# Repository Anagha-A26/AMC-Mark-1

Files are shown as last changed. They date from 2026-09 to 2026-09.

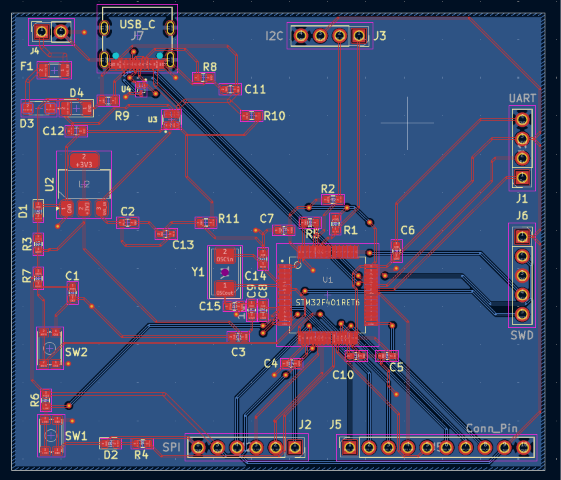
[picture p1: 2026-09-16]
STMt1/Images/PCB_Top.png

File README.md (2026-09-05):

# AMC-Mark-1
KiCad-based 2-layer STM32F401RE evaluation board with USB, UART, SPI, I²C, SWD, GPIO expansion, power regulation and user interfaces.

**STM32F401RE DEVELOPMENT BOARD**

**1. Selected MCU & Design Concept**

**Selected MCU**

**STM32F401RE / STM32F401RET6**

The **STM32F401RE** is selected as the core microcontroller for the evaluation board. It is based on an **Arm Cortex-M4 processor with Floating Point Unit (FPU)** and provides a broad set of peripherals, including GPIO, timers, ADC, UART/USART, SPI, I²C, USB 2.0 Full-Speed and SWD/JTAG debugging capabilities.
The MCU was selected because its peripheral set allows the major requirements of the evaluation board to be implemented around a **single central processing device**, while providing sufficient GPIO for external expansion.

**Why STM32F401RE?**

The core objective is to develop a **compact evaluation platform around the STM32F401RE** that allows users to:

- Program and debug the MCU through SWD.
- Communicate with a PC or USB host through USB.
- Experiment with UART, SPI and I²C peripherals.
- Access additional GPIOs for external circuits and modules.
- Interact with the board through user buttons and LEDs.
- Evaluate the MCU in a practical embedded-system development environment.

Thus, the STM32F401RE acts as the **central hub connecting the processing, communication, debugging and expansion interfaces**.

**Design Concept**

We propose a **compact, custom 2-layer STM32F401RE evaluation board** designed to provide convenient access to the MCU's processing, communication, debugging and GPIO capabilities.
The design is **functionally inspired by the STM32 NUCLEO-F401RE**, which provides STM32 development, Arduino compatibility, ST Morpho expansion and integrated ST-LINK debugging.
However, instead of reproducing the Nucleo architecture, our design independently implements the required functionality with a simpler and more focused architecture.

**Key design approach**

- **STM32F401RE** as the central MCU.
- **External ST-Link through SWD**, avoiding duplication of the on-board ST-LINK circuitry.
- **USB Type-C** providing direct USB 2.0 connectivity to the STM32.
- Dedicated and clearly labelled **UART, SPI and I²C interfaces**.
- **GPIO expansion headers** for external experimentation.
- Dedicated **reset button, user button, user LED and power indication**.
- Custom **power distribution, decoupling and grounding strategy**.
- Independently designed **2-layer PCB layout and routing** within the competition's 100 mm × 100 mm limit.

**Core Design Idea**

> To create a compact and accessible STM32F401RE evaluation platform that brings the MCU's major communication, debugging and GPIO capabilities onto a single independently designed 2-layer PCB, allowing users to program, debug and experiment with the MCU and external peripherals without reproducing the complete Nucleo architecture.

---

**Design Objectives**

1. Develop a functional **STM32F401RE evaluation platform**.
2. Provide **USB Type-C USB 2.0 connectivity** to the MCU.
3. Provide accessible **UART, SPI and I²C interfaces**.
4. Provide **SWD programming and debugging** using an external programmer/debugger.
5. Provide **user reset, user button, user LED and power indication**.
6. Provide **GPIO expansion headers** with power and ground.
7. Implement appropriate **power regulation and local decoupling**.
8. Develop a compact and electrically complete **2-layer PCB within 100 mm × 100 mm**.
9. Independently design the **schematic, component selection, placement, routing and silkscreen** rather than reproducing the reference board.

**2. BLOCK DIAGRAM**

ChatGPT Image Sep 5, 2026, 11_15_35 PM

**3. Schematic progress**




[View Schematic and PCB PDF](./schematic_pcb.pdf)

**4. Components Used**

| **Sl. No.** | **Component Type** | **Value / Part Number** | **Quantity** | **Section / Function** |
| --- | --- | --- | --- | --- |
| 1 | Microcontroller | STM32F401RET6 | 1 | Main MCU |
| 2 | Voltage Regulator | AMS1117-3.3 | 1 | 5 V to 3.3 V regulation |
| 3 | USB Type-C Connector | USB\_C\_Receptacle\_USB2.0\_16P | 1 | USB communication and 5 V input |
| 4 | Pin Header / Connector | Conn\_01x02\_Pin | 1 | External 5 V / GND connection |
| 5 | Pin Header | Conn\_01x05\_Pin | 1 | SWD programming/debugging |
| 6 | Pin Header | Conn\_01x04\_Pin | 1 | UART interface |
| 7 | Pin Header | Conn\_01x06\_Pin | 1 | SPI interface |
| 8 | Pin Header | Conn\_01x04\_Pin | 1 | I²C interface |
| 9 | Pin Header | Conn\_01x10\_Pin | 1 | GPIO expansion |
| 10 | Push Button | SW\_Push | 1 | User button |
| 11 | Push Button | SW\_Push | 1 | Reset button |
| 12 | LED | LED | 1 | Power ON indicator |
| 13 | LED | LED | 1 | User-programmable LED |
| 14 | Resistor | 4.7 kΩ | 1 | I²C SCL pull-up |
| 15 | Resistor | 4.7 kΩ | 1 | I²C SDA pull-up |
| 16 | Resistor | 1 kΩ | 1 | Power LED current limiting |
| 17 | Resistor | 330 Ω | 1 | User LED current limiting |
| 18 | Resistor | 10 kΩ | 1 | BOOT0 pull-down |
| 19 | Resistor | 10 kΩ | 1 | User button pull-up |
| 20 | Resistor | 10 kΩ | 1 | NRST pull-up |
| 21 | Resistor | 5.1 kΩ | 1 | USB-C CC1 pull-down |
| 22 | Resistor | 5.1 kΩ | 1 | USB-C CC2 pull-down |
| 23 | Capacitor | 10 µF | 1 | AMS1117 input capacitor |
| 24 | Capacitor | 10 µF | 1 | AMS1117 output capacitor |
| 25 | Power Multiplexer | TPS2116DRLR | 1 | Priority selection between USB-C 5 V and external 5 V power inputs |

**5. Major design decisions**

- Selected USB Type-C as the USB connector for communication and power input.
- Designed the board to accept 5 V power from either USB-C or an external 5 V connector.
- Selected the AMS1117-3.3 voltage regulator to generate the required 3.3 V supply.
- Used an external ST-Link through the SWD header instead of including an onboard ST-Link debugger.
- Selected PA11 and PA12 for USB D− and D+ communication.
- Selected PA9 and PA10 for UART TX and RX.
- Selected PA4, PA5, PA6 and PA7 for SPI communication.
- Selected PB6 and PB7 for I²C communication.
- Used 4.7 kΩ pull-up resistors for the I²C SCL and SDA lines.
- Used 5.1 kΩ pull-down resistors on CC1 and CC2 to configure the USB-C connector for device operation.
- Pulled BOOT0 to GND using a 10 kΩ resistor to ensure normal boot from internal Flash memory.
- Used separate headers for UART, SPI, I²C, SWD and GPIO expansion for easier testing and external interfacing.
- Selected additional unused MCU pins and brought them out through a dedicated GPIO expansion header.
- Used separate Power ON LED and User LED to distinguish power status from software-controlled indication.
- Chose a simple push-button reset circuit with a pull-up resistor for reliable manual reset.

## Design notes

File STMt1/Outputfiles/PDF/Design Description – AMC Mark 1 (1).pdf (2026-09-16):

# AMC Mark 1

### Team: AMC

1. Amal Manoj C
2. Anagha A
3. George Thomas

## 1. Design Objective

The proposed design is a compact, two-layer STM32F401RE-based evaluation and development board inspired by the functionality and architecture of the STM32 NUCLEO-F401RE. The objective is to provide a practical development platform with the essential facilities required for programming, debugging, power management, communication, GPIO expansion, and user interaction.

The board uses the STM32F401RET6 as the main microcontroller and integrates USB connectivity, regulated 3.3 V power, SWD programming/debugging, UART, SPI, I²C, GPIO expansion, user buttons, and status LEDs.

The design was developed independently using KiCad, with emphasis on compact component placement, reliable power distribution, organized routing, proper decoupling, and a clear PCB silkscreen.

The PCB was designed with a 70 mm × 60 mm board size, which is well within the competition's maximum permitted size of 100 mm × 100 mm. The design uses exactly two copper layers (Top and Bottom), with both layers utilized for efficient signal routing and power/ground distribution. The compact 70 mm × 60 mm form factor was chosen to achieve efficient component placement while maintaining clear routing, adequate spacing, and good overall board organization.

## 2. Main Components and Features

The major components and functional blocks incorporated in the board are:

- STM32F401RET6 – Main 32-bit ARM Cortex-M4 microcontroller
- USB Type-C interface – USB connectivity for the board
- TPS2116DRL power multiplexer – Power-source selection/management
- AMS1117-3.3 regulator – Generation of the regulated 3.3 V supply
- TPD2EUSB30 – USB protection
- SWD header – Programming and debugging interface

- UART header – Serial communication
- SPI header – High-speed peripheral communication
- I²C header – Two-wire peripheral communication
- GPIO expansion header – Access to STM32 GPIO pins
- Reset button – Hardware reset functionality
- User button – General-purpose user input
- User LED – User/status indication
- Power LED – Power status indication
- Crystal oscillator – External clock source for the microcontroller
- Decoupling capacitors – Local power-supply stabilization
- Protection components – Input and USB protection

## 3. Power Architecture

The power architecture was designed to support both USB-C 5 V and an external 5 V input. The TPS2116DRL power multiplexer provides controlled power-source selection and supplies the SYS_5V rail. This is followed by the AMS1117-3.3 regulator, which generates the regulated 3.3 V supply for the STM32F401RET6 and associated peripherals. This architecture provides a flexible power-input arrangement while maintaining a regulated supply for the low-voltage circuitry.

The basic power flow is

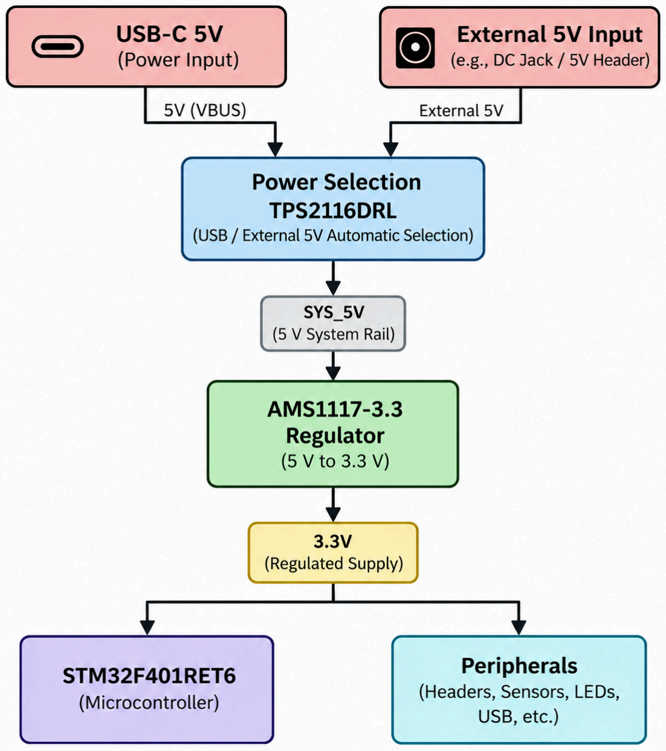
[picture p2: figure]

The power architecture supports two 5 V input sources: USB-C 5 V and an external 5 V supply. These inputs are connected to the TPS2116DRL power multiplexer, which provides controlled selection and distribution of the available power source to the SYS_5V rail. The SYS_5V rail then feeds the AMS1117-3.3 regulator, which generates the regulated 3.3 V supply required by the STM32F401RET6 and associated low-voltage circuitry.

A dedicated power LED provides visual indication that the board is powered. The resulting architecture provides the essential functionality required for an STM32 evaluation and development platform while maintaining a compact PCB implementation.

## 4. PCB Design

The PCB was designed as a two-layer board, consisting of top and bottom copper layers. The maximum permitted board size for the competition is 100 mm × 100 mm, and the board layout was developed within this constraint.

Component placement was carried out according to functional requirements and routing convenience. The STM32F401RET6 is positioned as the central processing element, while connectors and interfaces are arranged around the board to provide convenient access during development.

The major PCB design considerations were

- Compact component placement
- Proper power and ground distribution
- Short connections for critical power paths
- Appropriate placement of decoupling capacitors
- Organized signal routing
- Separation and organization of different functional interfaces
- Efficient use of both copper layers
- Accessible programming and communication headers
- Clear and readable PCB silkscreen

The final PCB passed the KiCad DRC with zero errors, with zero unrouted connections. The silkscreen was also organized to clearly identify important connectors, interfaces, power rails, and user controls.

## 5. Interfaces

### 5.1 SWD Interface

A dedicated SWD (Serial Wire Debug) header is provided for programming and debugging the STM32F401RET6. The interface provides the required connections.

- SWDIO
- SWCLK
- NRST
- VCC
- GND

The ST-Link circuitry itself is not included on the board, as it is not required by the competition specification. An external ST-Link programmer/debugger can therefore be connected through the SWD header.

### 5.2 UART Interface

A dedicated UART header is provided for serial communication with external devices. This interface can be used for debugging, terminal communication, data logging, and communication with other embedded systems.

### 5.3 SPI Interface

An SPI header provides access to the STM32 SPI peripheral signals. It can be used to interface external sensors, displays, memory devices, ADCs, DACs, and other SPI-compatible peripherals.

### 5.4 I²C Interface

An I²C header is provided for connecting multiple peripheral devices using the two-wire I²C communication protocol. This makes the board suitable for interfacing sensors, displays, EEPROMs, and other I²C devices.

### 5.5 USB Interface

A USB Type-C connector is provided as the primary USB interface. The USB section also includes dedicated protection circuitry to improve the robustness of the USB connection.

### 5.6 GPIO Expansion

A dedicated GPIO expansion header provides access to selected STM32 GPIO, power, and ground connections. This allows external circuits and modules to be connected easily during development and experimentation.

## 6. Design Decisions

Several design decisions were made to achieve a compact and functional evaluation board.

Power Management

The power architecture was designed to support both USB-C 5 V and an external 5 V input. The TPS2116DRL power multiplexer provides controlled power-source selection and supplies the SYS_5V rail. This is followed by the AMS1117-3.3 regulator, which generates the regulated 3.3 V supply for the STM32F401RET6 and associated peripherals. This architecture provides a flexible power-input arrangement while maintaining a regulated supply for the low-voltage circuitry.

Component Placement

The STM32F401RET6 was positioned as the central component of the PCB, with supporting power and clock components placed close to the MCU. Connectors were positioned around the board edges where possible to make external connections easier.

Interface Organization

Communication and programming interfaces were separated into dedicated headers for SWD, UART, SPI, and I²C. This makes the board easier to use and allows different peripherals or debugging equipment to be connected without interfering with other interfaces.

Routing Optimization

The PCB routing was planned to minimize unnecessary trace lengths and reduce routing complexity. Power connections and important signal paths were given appropriate routing consideration, while the two copper layers were utilized efficiently to complete the design within the board-size and layer constraints.

Ground and Power Distribution

Ground and power connections were distributed throughout the PCB with attention to maintaining reliable connections between the power supply, microcontroller, and peripheral circuits. Decoupling capacitors were placed near relevant power pins to provide local supply stabilization.

Silkscreen and Usability

Clear silkscreen labels were provided for major connectors, interfaces, power rails, buttons, LEDs, and other important board features. This improves usability by allowing users to identify the purpose and pin functions of the different headers directly from the PCB.

## 7. Conclusion

The resulting STM32F401RE evaluation board provides a compact and organized development platform centered around the STM32F401RET6 microcontroller. It integrates regulated power, USB connectivity, SWD debugging, UART, SPI, I²C, GPIO expansion, user controls, and status indicators in a two-layer PCB.

The design focuses on electrical completeness, practical component placement, organized routing, power integrity, and usability. The PCB was developed independently in KiCad while using the STM32 NUCLEO-F401RE as a functional reference, in accordance with the competition requirements. The final design is intended to provide a practical platform for STM32-based embedded development and peripheral interfacing.

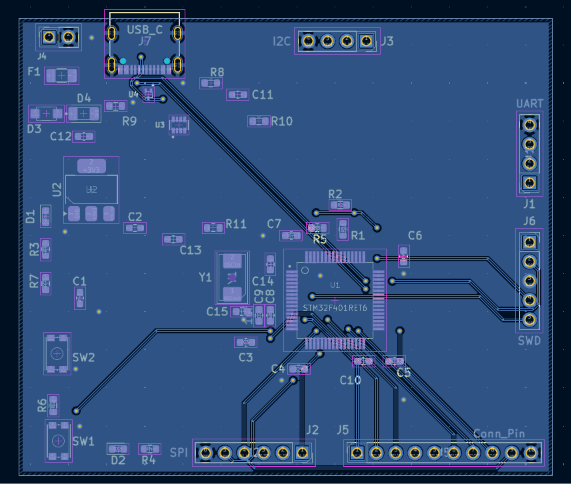
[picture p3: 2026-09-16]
STMt1/Images/PCB_Bottom.png

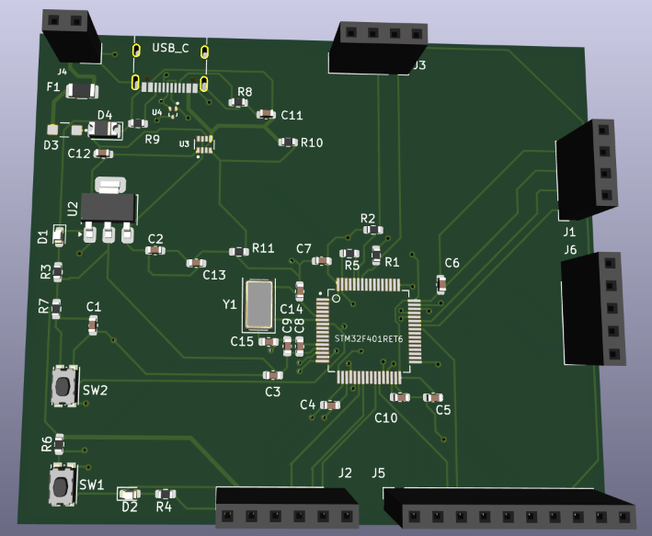
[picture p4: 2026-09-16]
STMt1/Images/PCB_3D_Front.png

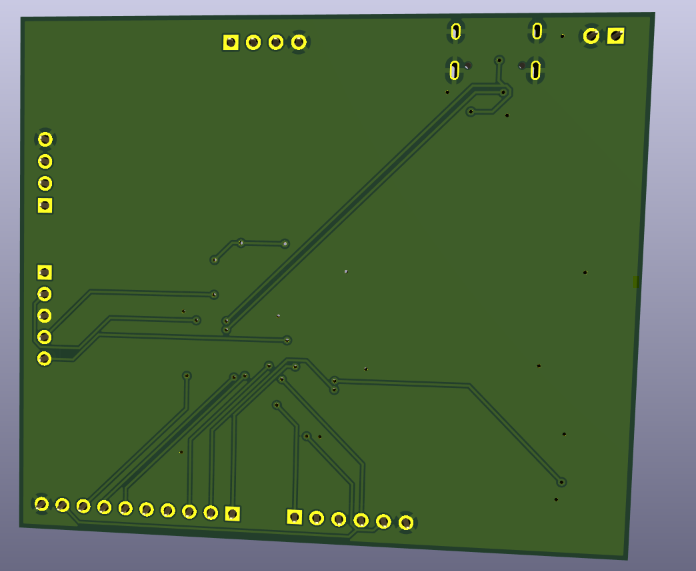
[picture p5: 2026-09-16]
STMt1/Images/PCB_3D_Back.png

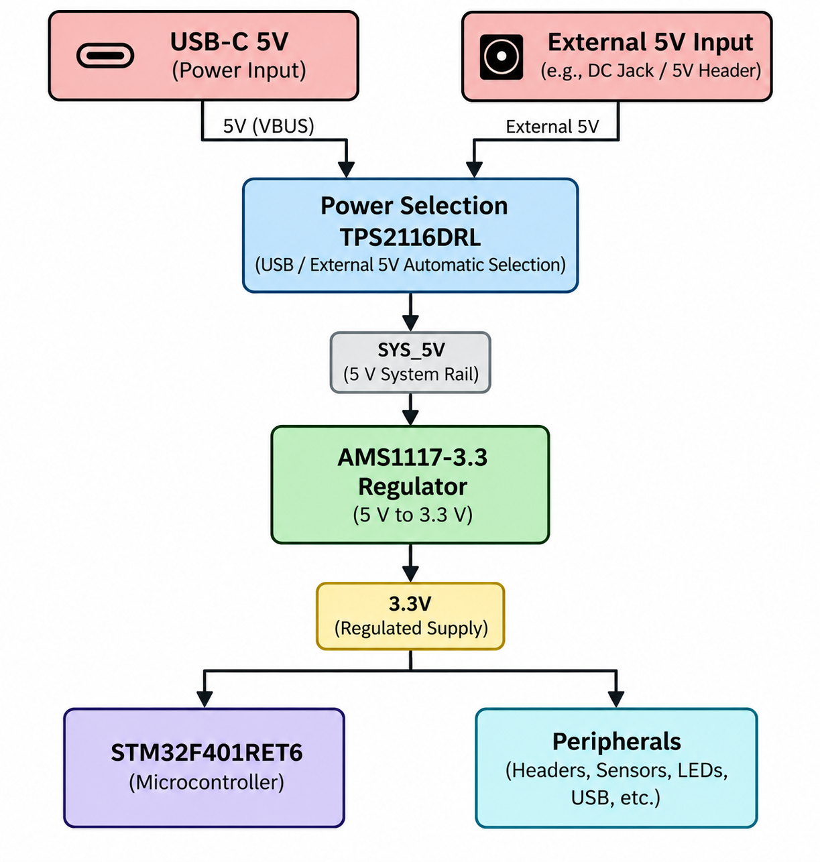
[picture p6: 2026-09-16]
STMt1/Images/Power_Arch.png

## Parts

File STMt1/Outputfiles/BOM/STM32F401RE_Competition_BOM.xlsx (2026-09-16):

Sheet: Competition BOM
STM32F401RE Evaluation Board – Competition BOM
AMC Mark 1 Estimated component cost in INR
Reference | Qty | Value / Part | Footprint | Unit Cost (₹) | Total Cost (₹) | Price Basis / Note
C1,C4,C5,C6,C7,C8 | 6 | 100nF | Capacitor_SMD:C_0603_1608Metric | ₹0.50 | ₹3.00 | Indicative India component price
C2,C3,C11,C12,C13 | 5 | 10uF | Capacitor_SMD:C_0603_1608Metric | ₹1.50 | ₹7.50 | Indicative India component price
C9 | 1 | 1uF | Capacitor_SMD:C_0603_1608Metric | ₹0.60 | ₹0.60 | Indicative India component price
C10 | 1 | 2.2uF | Capacitor_SMD:C_0603_1608Metric | ₹0.80 | ₹0.80 | Indicative India component price
C14,C15 | 2 | 18pF | Capacitor_SMD:C_0603_1608Metric | ₹0.50 | ₹1.00 | Indicative India component price
D1,D2 | 2 | LED | LED_SMD:LED_0603_1608Metric | ₹1.00 | ₹2.00 | Indicative India component price
D3 | 1 | 1N5819W Schottky | 1N5819W:SODFL3618X110N | ₹3.00 | ₹3.00 | Indicative India component price
D4 | 1 | D_TVS | Diode_SMD:D_1206_3216Metric | ₹7.00 | ₹7.00 | Indicative India component price
F1 | 1 | Polyfuse | Fuse:Fuse_1206_3216Metric | ₹5.00 | ₹5.00 | Indicative India component price
J1 | 1 | UART | 1x04 2.54mm vertical header | ₹4.00 | ₹4.00 | Indicative India component price
J2 | 1 | SPI | 1x06 2.54mm vertical header | ₹6.00 | ₹6.00 | Indicative India component price
J3 | 1 | I2C | 1x04 2.54mm vertical header | ₹4.00 | ₹4.00 | Indicative India component price
J4 | 1 | 5V | 1x02 2.54mm vertical header | ₹2.50 | ₹2.50 | Indicative India component price
J5 | 1 | GPIO Expansion | 1x10 2.54mm vertical header | ₹10.00 | ₹10.00 | Indicative India component price
J6 | 1 | SWD | 1x05 2.54mm vertical header | ₹5.00 | ₹5.00 | Indicative India component price
J7 | 1 | GT-USB-7010ASV USB-C | Connector_USB:USB_C_Receptacle_G-Switch_GT-USB-7010ASV | ₹8.00 | ₹8.00 | LCSC listing indicates low-cost part; ₹8 used as practical India estimate
R1,R2 | 2 | 4.7k | Resistor_SMD:R_0603_1608Metric | ₹0.25 | ₹0.50 | Indicative India component price
R3 | 1 | 1k | Resistor_SMD:R_0603_1608Metric | ₹0.25 | ₹0.25 | Indicative India component price
R4 | 1 | 330E | Resistor_SMD:R_0603_1608Metric | ₹0.25 | ₹0.25 | Indicative India component price
R5,R6,R7,R11 | 4 | 10k | Resistor_SMD:R_0603_1608Metric | ₹0.25 | ₹1.00 | Indicative India component price
R8,R9 | 2 | 5.1k | Resistor_SMD:R_0603_1608Metric | ₹0.25 | ₹0.50 | Indicative India component price
R10 | 1 | 33k | Resistor_SMD:R_0603_1608Metric | ₹0.25 | ₹0.25 | Indicative India component price
SW1,SW2 | 2 | SW_Push / KMR2 | Button_Switch_SMD:SW_Push_1P1T_NO_CK_KMR2 | ₹45.00 | ₹90.00 | C&K KMR2 class; ₹45 used as practical estimate
U1 | 1 | STM32F401RET6 | STM32F401RET6:QFP50P1200X1200X160-64N | ₹714.69 | ₹714.69 | Mouser India, 1-piece indicative price
U2 | 1 | AMS1117-3.3 | Package_TO_SOT_SMD:SOT-223-3_TabPin2 | ₹4.90 | ₹4.90 | Indian distributor indicative price
U3 | 1 | TPS2116DRL | TPS2116DRLR:SOTFL50P160X60-8N | ₹45.00 | ₹45.00 | Indicative India component price
U4 | 1 | TPD2EUSB30ADRTR | TPD2EUSB30ADRTR:SOTFL35P100X50-3N | ₹94.11 | ₹94.11 | Mouser/DigiKey India 1-piece indicative price
Y1 | 1 | 8MHz | Crystal:Crystal_SMD_0603-2Pin_6.0x3.5mm | ₹8.00 | ₹8.00 | Indicative India component price
 |  |  |  | GRAND TOTAL | ₹1028.85
Submission Notes
• This BOM is based on the user's exported KiCad BOM (STMt1.csv).
• Prices are estimated component costs for competition documentation, not a supplier quotation.
• Major IC prices were checked against current Indian distributor listings where available.
• PCB fabrication, assembly, shipping, and taxes are NOT included in the component BOM total.
• For final procurement, replace estimates with supplier quotations/invoices if required.

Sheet: Cost Summary
Category | Estimated Cost (₹)
MCU | ₹714.69
Power / Protection ICs | ₹159.01
USB / Headers | ₹39.50
Passives | ₹15.65
LEDs | ₹2.00
Switches | ₹90.00
Crystal | ₹8.00
TOTAL | ₹1028.85

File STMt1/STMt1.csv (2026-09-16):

Reference | Qty | Value | DNP | Exclude from BOM | Exclude from Board | Footprint | Datasheet
C1,C4,C5,C6,C7,C8 | 6 | 100nf |  |  |  | Capacitor_SMD:C_0603_1608Metric | ~
C2,C3,C11,C12,C13 | 5 | 10uf |  |  |  | Capacitor_SMD:C_0603_1608Metric | ~
C9 | 1 | 1uf |  |  |  | Capacitor_SMD:C_0603_1608Metric | ~
C10 | 1 | 2.2uf |  |  |  | Capacitor_SMD:C_0603_1608Metric | ~
C14,C15 | 2 | 18pF |  |  |  | Capacitor_SMD:C_0603_1608Metric | ~
D1,D2 | 2 | LED |  |  |  | LED_SMD:LED_0603_1608Metric | ~
D3 | 1 | D_Schottky |  |  |  | 1N5819W:SODFL3618X110N | ~
D4 | 1 | D_TVS |  |  |  | Diode_SMD:D_1206_3216Metric | ~
F1 | 1 | Polyfuse |  |  |  | Fuse:Fuse_1206_3216Metric | ~
J1 | 1 | UART |  |  |  | Connector_PinSocket_2.54mm:PinSocket_1x04_P2.54mm_Vertical | ~
J2 | 1 | SPI |  |  |  | Connector_PinSocket_2.54mm:PinSocket_1x06_P2.54mm_Vertical | ~
J3 | 1 | I2C |  |  |  | Connector_PinSocket_2.54mm:PinSocket_1x04_P2.54mm_Vertical | ~
J4 | 1 | 5V |  |  |  | Connector_PinSocket_2.54mm:PinSocket_1x02_P2.54mm_Vertical | ~
J5 | 1 | Conn_01x10_Pin |  |  |  | Connector_PinSocket_2.54mm:PinSocket_1x10_P2.54mm_Vertical | ~
J6 | 1 | SWD |  |  |  | Connector_PinSocket_2.54mm:PinSocket_1x05_P2.54mm_Vertical | ~
J7 | 1 | USB_C_Receptacle_USB2.0_16P |  |  |  | Connector_USB:USB_C_Receptacle_G-Switch_GT-USB-7010ASV | https://www.usb.org/sites/default/files/documents/usb_type-c.zip
R1,R2 | 2 | 4.7k |  |  |  | Resistor_SMD:R_0603_1608Metric | ~
R3 | 1 | 1k |  |  |  | Resistor_SMD:R_0603_1608Metric | ~
R4 | 1 | 330E |  |  |  | Resistor_SMD:R_0603_1608Metric | ~
R5,R6,R7,R11 | 4 | 10k |  |  |  | Resistor_SMD:R_0603_1608Metric | ~
R8,R9 | 2 | 5.1k |  |  |  | Resistor_SMD:R_0603_1608Metric | ~
R10 | 1 | 33k |  |  |  | Resistor_SMD:R_0603_1608Metric | ~
SW1,SW2 | 2 | SW_Push |  |  |  | Button_Switch_SMD:SW_Push_1P1T_NO_CK_KMR2 | ~
U1 | 1 | STM32F401RET6 |  |  |  | STM32F401RET6:QFP50P1200X1200X160-64N | https://www.st.com/resource/en/datasheet/stm32f401re.pdf
U2 | 1 | AMS1117-3.3 |  |  |  | Package_TO_SOT_SMD:SOT-223-3_TabPin2 | http://www.advanced-monolithic.com/pdf/ds1117.pdf
U3 | 1 | TPS2116DRL |  |  |  | TPS2116DRLR:SOTFL50P160X60-8N | https://www.ti.com/lit/ds/symlink/tps2116.pdf
U4 | 1 | TPD2EUSB30 |  |  |  | TPD2EUSB30ADRTR:SOTFL35P100X50-3N | http://www.ti.com/lit/ds/symlink/tpd2eusb30a.pdf
Y1 | 1 | 8MHz |  |  |  | Crystal:Crystal_SMD_0603-2Pin_6.0x3.5mm | ~

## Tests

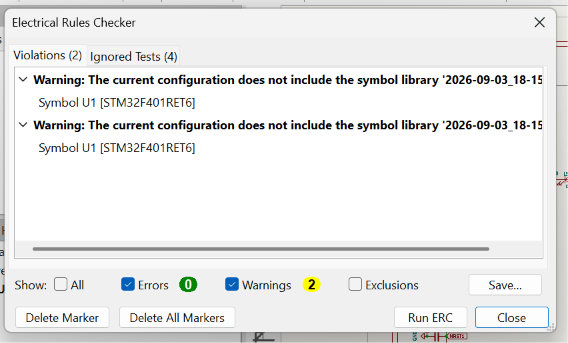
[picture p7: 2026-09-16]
STMt1/Images/ERC_Result.png

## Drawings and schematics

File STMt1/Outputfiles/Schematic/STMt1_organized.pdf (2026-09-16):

1 | GND3 | D-2 U4 TPD2EUSB30 VIN1 3 PR1 4 MODE 5 VIN2 6 | GND
BOOT0 60 | NRST 7 | PB0 26 | PB1 27 | PB2 28 | PB3 55 | PB4 56 | PB5 57 | PB6 58 | PB7 59 | PB8 61 | PB9 62 | PB10 29 | PB12 33 | PB13 34 | PB14 35 | PB15 36 | PD2 54 | PH0-OSC_IN 5 | PH1 6 | PA0 | 14 PA1 | 15 PA2 | 16 PA3 | 17 PA4 | 20 PA5 | 21 PA6 | 22 PA7 | 23 PA8 | 41 PA9 | 42 PA10 | 43 PA11 | 44 PA12 | 45 PA13 | 46 PA14 | 49 PA15 | 50 PC0 | 8 PC1 | 9 PC2 | 10 PC3 | 11 PC4 | 24 PC5 | 25 PC6 | 37 PC7 | 38 PC8 | 39 PC9 | 40 PC10 | 51 PC11 | 52 PC12 | 53 PC13 | 2 PC14-OSC32_IN | 3 PC15-OSC32_OUT | 4 U1A

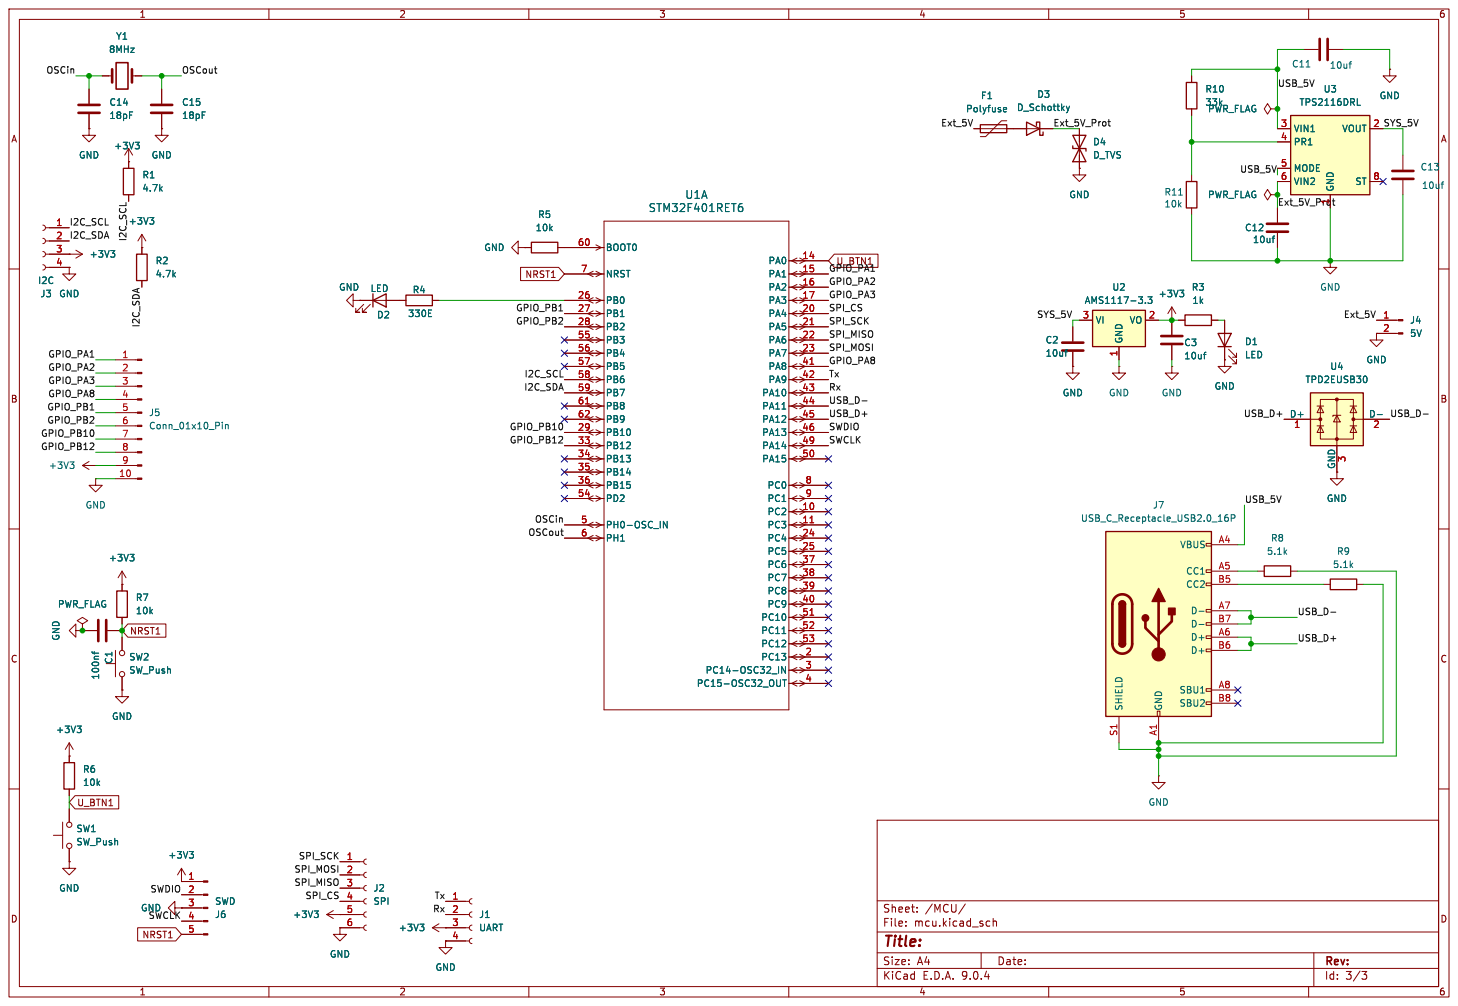
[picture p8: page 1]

Id: 3/3 Title: File: mcu.kicad_sch Sheet: /MCU/

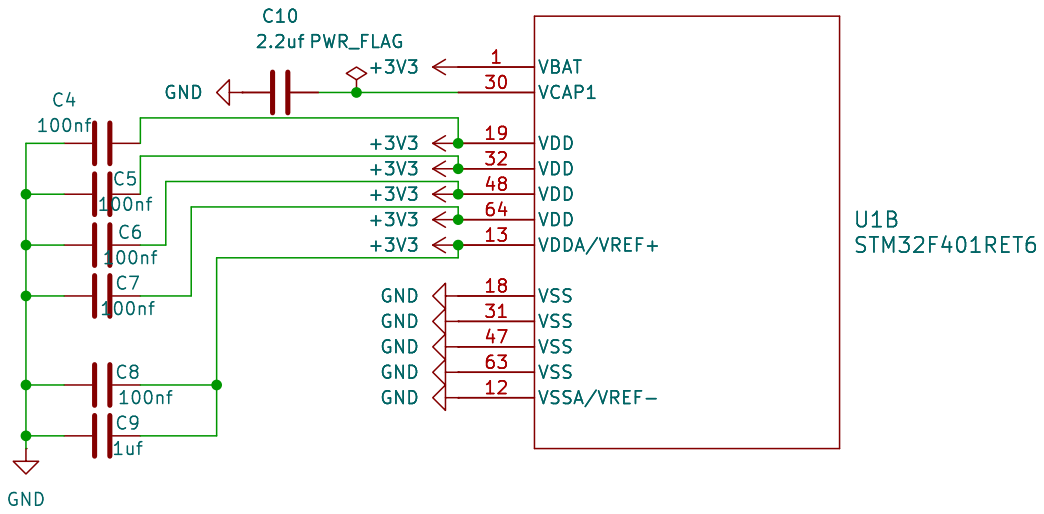
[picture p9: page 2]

Id: 2/3 Title: File: power.kicad_sch Sheet: /Power/ GND GND

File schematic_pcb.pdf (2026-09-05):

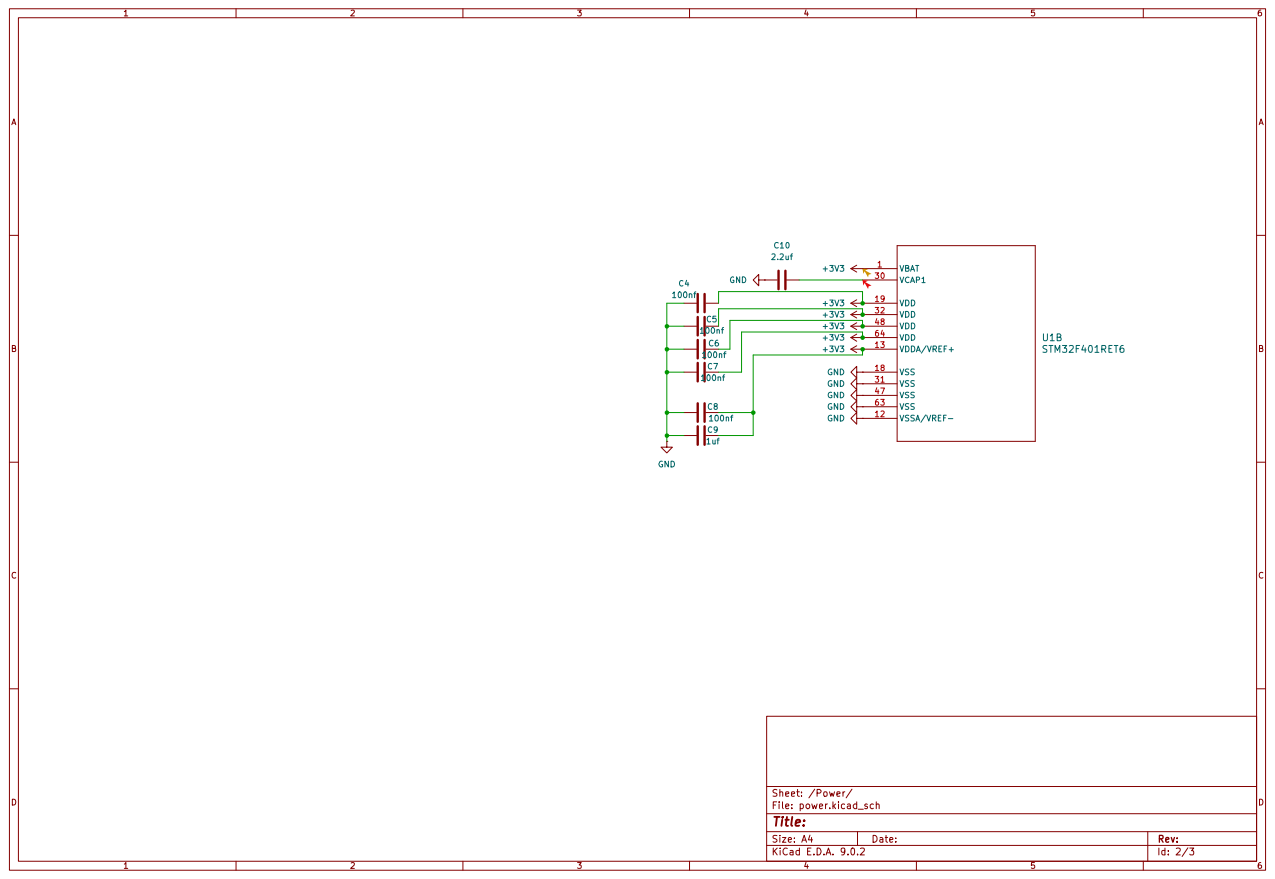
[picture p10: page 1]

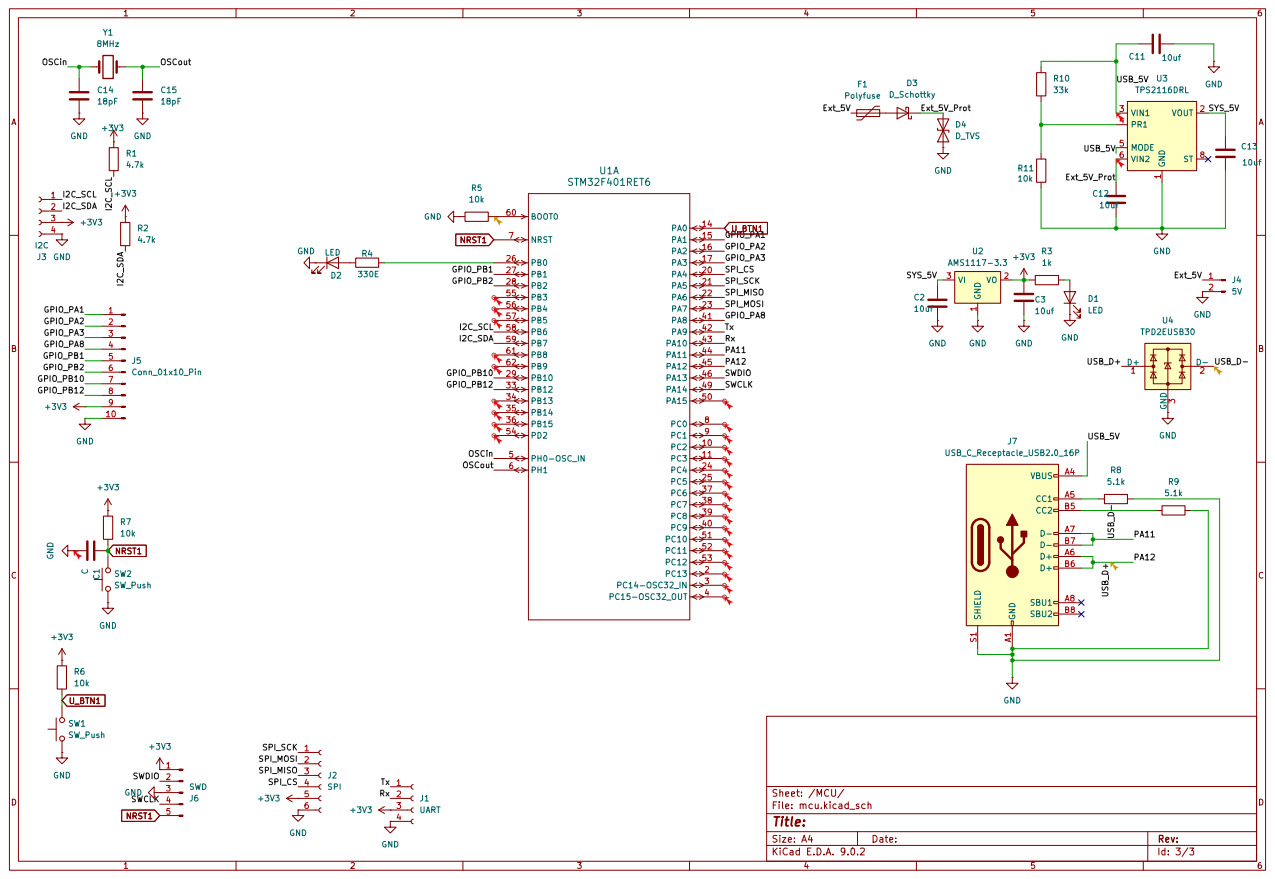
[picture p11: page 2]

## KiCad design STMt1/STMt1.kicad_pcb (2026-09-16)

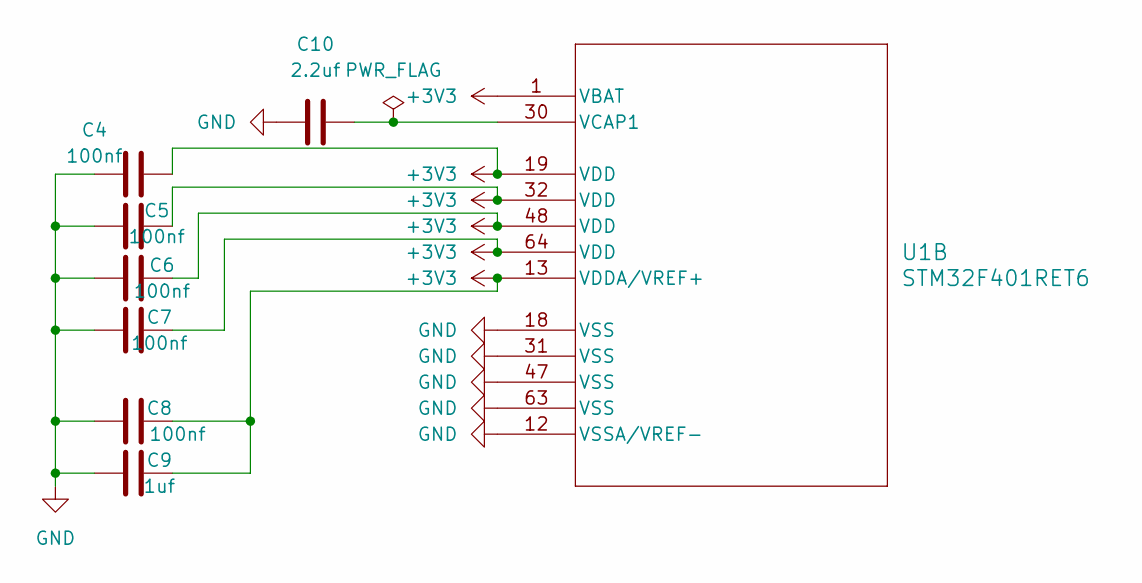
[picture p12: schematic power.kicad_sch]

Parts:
C4, C5, C6, C7, C8: 100nf; C_0603_1608Metric
C9: 1uf; C_0603_1608Metric
C10: 2.2uf; C_0603_1608Metric
U1: STM32F401RET6; QFP50P1200X1200X160-64N

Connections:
+3V3: C4.2, C5.2, C6.2, C7.2, C8.2, C9.2, U1.1 (VBAT), U1.13 (VDDA/VREF+), U1.19 (VDD), U1.32 (VDD), U1.48 (VDD), U1.64 (VDD); also elsewhere on the board
GND: C4.1, C5.1, C6.1, C7.1, C8.1, C9.1, C10.1, U1.12 (VSSA/VREF-), U1.18 (VSS), U1.31 (VSS), U1.47 (VSS), U1.63 (VSS); also elsewhere on the board
unnamed 36: C10.2, U1.30 (VCAP1); also elsewhere on the board

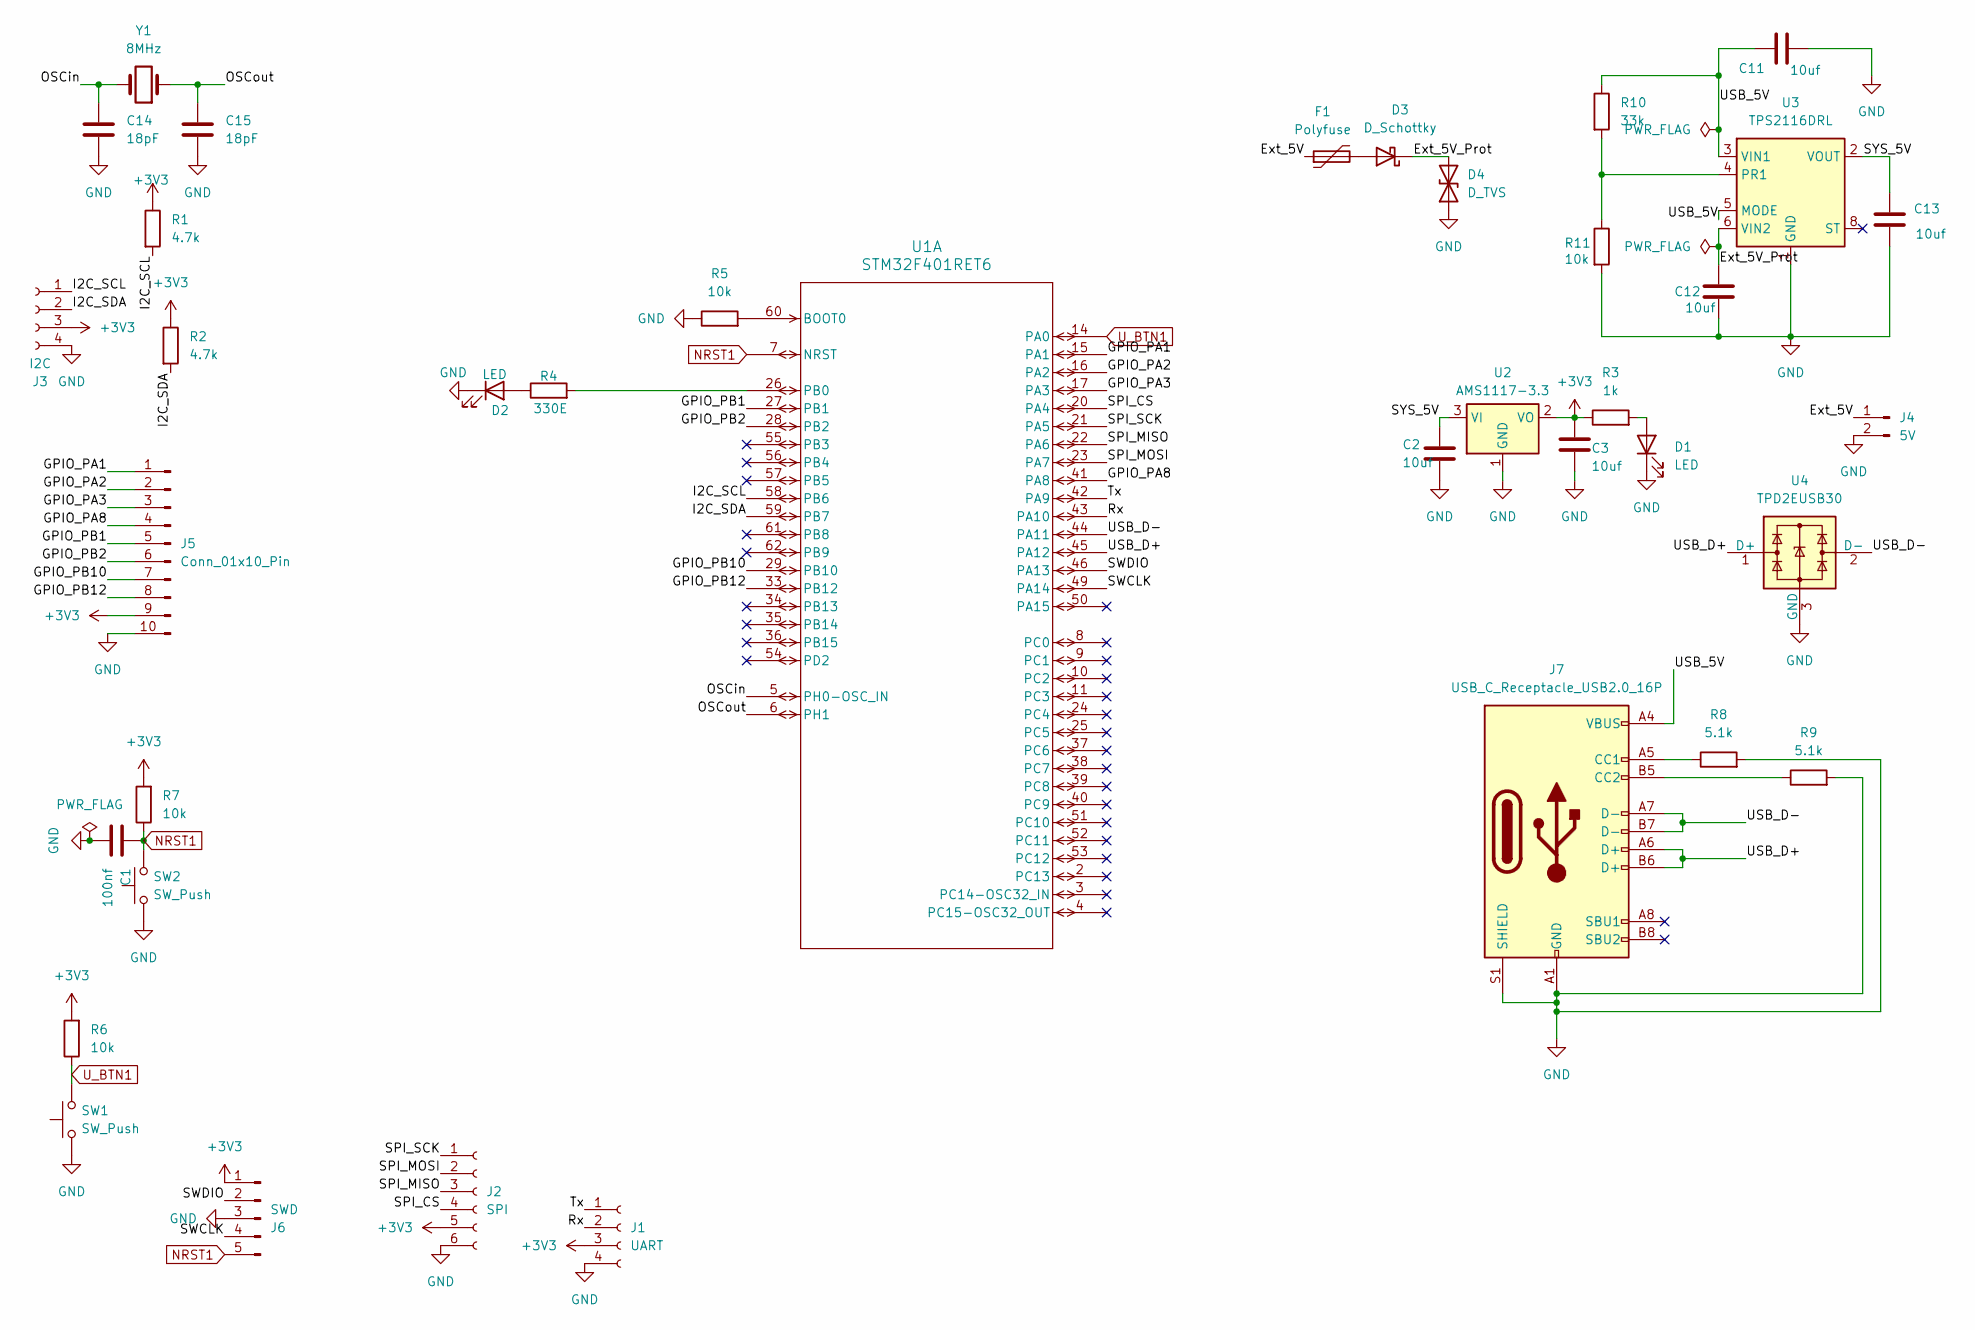
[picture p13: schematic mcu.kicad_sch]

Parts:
C1: 100nf; C_0603_1608Metric
C2, C3, C11, C12, C13: 10uf; C_0603_1608Metric
C14, C15: 18pF; C_0603_1608Metric
D1, D2: LED; LED_0603_1608Metric
D3: D_Schottky; SODFL3618X110N
D4: D_TVS; D_1206_3216Metric
F1: Polyfuse; Fuse_1206_3216Metric
J1: UART; PinSocket_1x04_P2.54mm_Vertical
J2: SPI; PinSocket_1x06_P2.54mm_Vertical
J3: I2C; PinSocket_1x04_P2.54mm_Vertical
J4: 5V; PinSocket_1x02_P2.54mm_Vertical
J5: Conn_01x10_Pin; PinSocket_1x10_P2.54mm_Vertical
J6: SWD; PinSocket_1x05_P2.54mm_Vertical
J7: USB_C_Receptacle_USB2.0_16P; USB_C_Receptacle_G-Switch_GT-USB-7010ASV
R1, R2: 4.7k; R_0603_1608Metric
R3: 1k; R_0603_1608Metric
R4: 330E; R_0603_1608Metric
R5, R6, R7, R11: 10k; R_0603_1608Metric
R8, R9: 5.1k; R_0603_1608Metric
R10: 33k; R_0603_1608Metric
SW1, SW2: SW_Push; SW_Push_1P1T_NO_CK_KMR2
U1: STM32F401RET6; QFP50P1200X1200X160-64N
U2: AMS1117-3.3; SOT-223-3_TabPin2
U3: TPS2116DRL; SOTFL50P160X60-8N
U4: TPD2EUSB30; SOTFL35P100X50-3N
Y1: 8MHz; Crystal_SMD_0603-2Pin_6.0x3.5mm

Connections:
+3V3: C3.1, J1.3, J2.5, J3.3, J5.9, J6.1, R1.1, R2.1, R3.1, R6.2, R7.2, U2.2 (VO); also elsewhere on the board
/MCU/Ext_5V: F1.1, J4.1
/MCU/Ext_5V_Prot: C12.1, D3.1 (K), D4.2 (A2), U3.6 (VIN2)
/MCU/GPIO_PA1: J5.1, U1.15 (PA1); also elsewhere on the board
/MCU/GPIO_PA2: J5.2, U1.16 (PA2); also elsewhere on the board
/MCU/GPIO_PA3: J5.3, U1.17 (PA3); also elsewhere on the board
/MCU/GPIO_PA8: J5.4, U1.41 (PA8); also elsewhere on the board
/MCU/GPIO_PB1: J5.5, U1.27 (PB1); also elsewhere on the board
/MCU/GPIO_PB2: J5.6, U1.28 (PB2); also elsewhere on the board
/MCU/GPIO_PB10: J5.7, U1.29 (PB10); also elsewhere on the board
/MCU/GPIO_PB12: J5.8, U1.33 (PB12); also elsewhere on the board
/MCU/I2C_SCL: J3.1, R1.2, U1.58 (PB6); also elsewhere on the board
/MCU/I2C_SDA: J3.2, R2.2, U1.59 (PB7); also elsewhere on the board
/MCU/OSCin: C14.1, U1.5 (PH0-OSC_IN), Y1.2; also elsewhere on the board
/MCU/OSCout: C15.1, U1.6 (PH1), Y1.1; also elsewhere on the board
/MCU/Rx: J1.2, U1.43 (PA10); also elsewhere on the board
/MCU/SPI_CS: J2.4, U1.20 (PA4); also elsewhere on the board
/MCU/SPI_MISO: J2.3, U1.22 (PA6); also elsewhere on the board
/MCU/SPI_MOSI: J2.2, U1.23 (PA7); also elsewhere on the board
/MCU/SPI_SCK: J2.1, U1.21 (PA5); also elsewhere on the board
/MCU/SWCLK: J6.4, U1.49 (PA14); also elsewhere on the board
/MCU/SWDIO: J6.2, U1.46 (PA13); also elsewhere on the board
/MCU/SYS_5V: C2.1, C13.1, U2.3 (VI), U3.2 (VOUT), U3.7 (VOUT)
/MCU/Tx: J1.1, U1.42 (PA9); also elsewhere on the board
/MCU/USB_5V: C11.1, J7.A4 (VBUS), J7.A9 (VBUS), J7.B4 (VBUS), J7.B9 (VBUS), R10.1, U3.3 (VIN1), U3.5 (MODE)
/MCU/USB_D+: J7.A6 (D+), J7.B6 (D+), U1.45 (PA12), U4.1 (D+); also elsewhere on the board
/MCU/USB_D-: J7.A7 (D-), J7.B7 (D-), U1.44 (PA11), U4.2 (D-); also elsewhere on the board
GND: C1.2, C2.2, C3.2, C11.2, C12.2, C13.2, C14.2, C15.2, D1.1 (K), D2.1 (K), D4.1 (A1), J1.4, J2.6, J3.4, J4.2, J5.10, J6.3, J7.A1 (GND), J7.A12 (GND), J7.B1 (GND), J7.B12 (GND), J7.S1 (SHIELD), R5.1, R8.2, R9.2, R11.2, SW1.1, SW2.1, U2.1 (GND), U3.1 (GND), U4.3 (GND); also elsewhere on the board
NRST1: C1.1, J6.5, R7.1, SW2.2, U1.7 (NRST); also elsewhere on the board
unnamed: D1.2 (A), R3.2
unnamed: D2.2 (A), R4.1
unnamed: D3.2 (A), F1.2
unnamed: J7.A5 (CC1), R8.1
unnamed: J7.B5 (CC2), R9.1
unnamed 34: R5.2, U1.60 (BOOT0); also elsewhere on the board
unnamed 35: R4.2, U1.26 (PB0); also elsewhere on the board
unnamed: R10.2, R11.1, U3.4 (PR1)
U_BTN1: R6.1, SW1.2, U1.14 (PA0); also elsewhere on the board

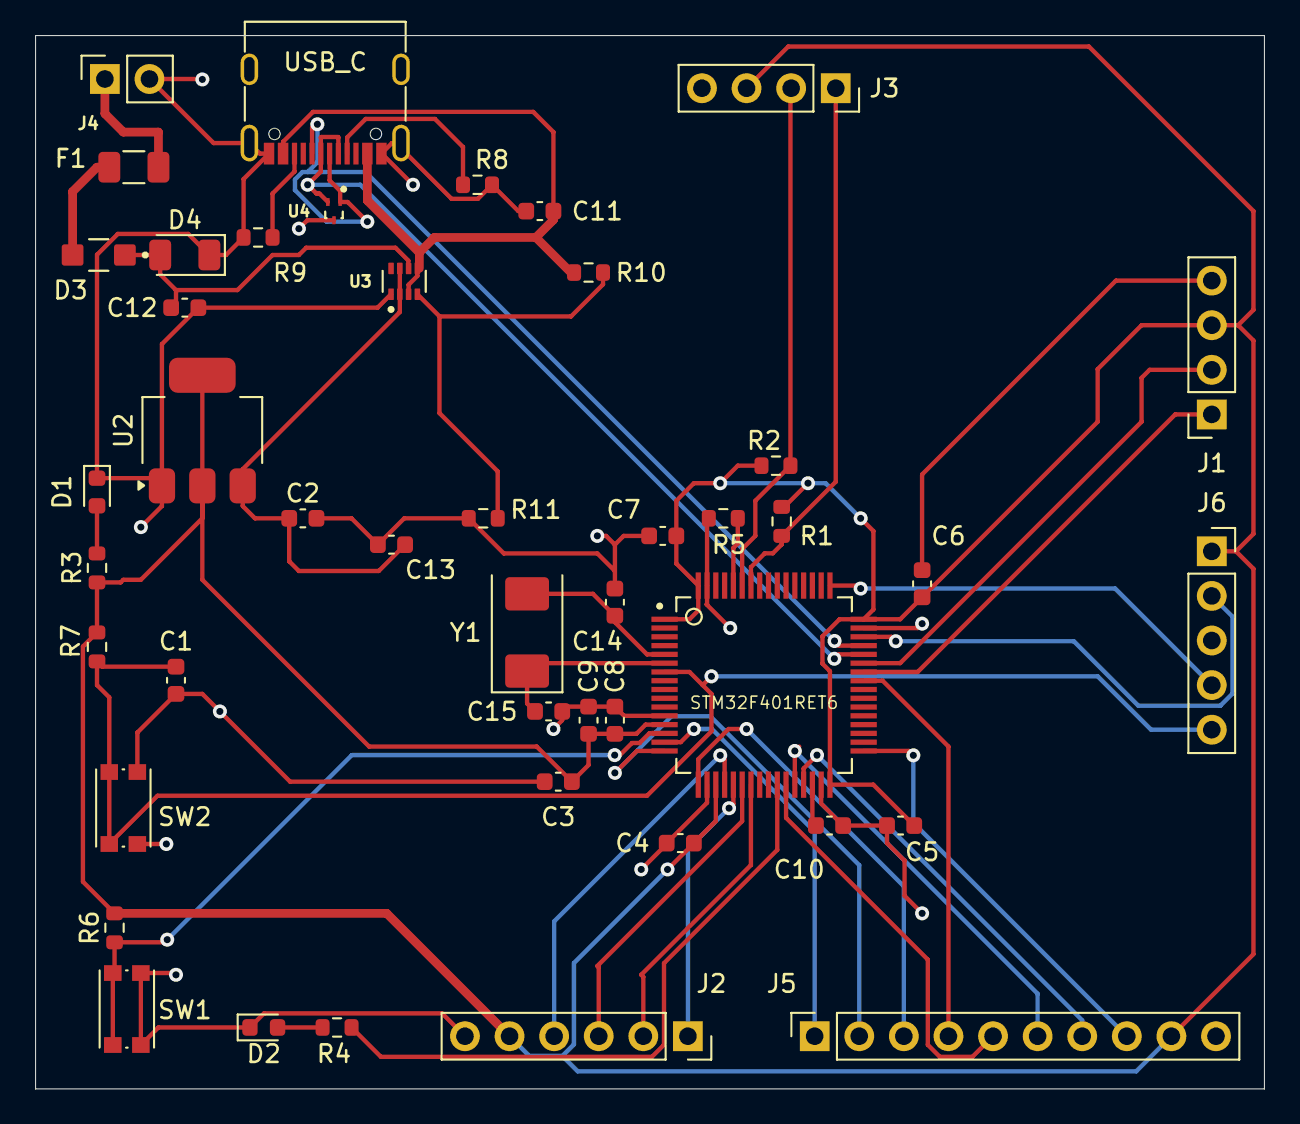
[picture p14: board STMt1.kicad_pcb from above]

Board: 2 copper layers, 70.0 x 60.0 mm, 45 parts (0 on the bottom side), 39 nets.

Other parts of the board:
STM32F401RET6: U1; QFP50P1200X1200X160-64N

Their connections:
+3V3: STM32F401RET6.1 (VBAT), STM32F401RET6.13 (VDDA/VREF+), STM32F401RET6.19 (VDD), STM32F401RET6.32 (VDD), STM32F401RET6.48 (VDD), STM32F401RET6.64 (VDD); also elsewhere on the board
/MCU/GPIO_PA1: STM32F401RET6.15 (PA1); also elsewhere on the board
/MCU/GPIO_PA2: STM32F401RET6.16 (PA2); also elsewhere on the board
/MCU/GPIO_PA3: STM32F401RET6.17 (PA3); also elsewhere on the board
/MCU/GPIO_PA8: STM32F401RET6.41 (PA8); also elsewhere on the board
/MCU/GPIO_PB1: STM32F401RET6.27 (PB1); also elsewhere on the board
/MCU/GPIO_PB2: STM32F401RET6.28 (PB2); also elsewhere on the board
/MCU/GPIO_PB10: STM32F401RET6.29 (PB10); also elsewhere on the board
/MCU/GPIO_PB12: STM32F401RET6.33 (PB12); also elsewhere on the board
/MCU/I2C_SCL: STM32F401RET6.58 (PB6); also elsewhere on the board
/MCU/I2C_SDA: STM32F401RET6.59 (PB7); also elsewhere on the board
/MCU/OSCin: STM32F401RET6.5 (PH0-OSC_IN); also elsewhere on the board
/MCU/OSCout: STM32F401RET6.6 (PH1); also elsewhere on the board
/MCU/Rx: STM32F401RET6.43 (PA10); also elsewhere on the board
/MCU/SPI_CS: STM32F401RET6.20 (PA4); also elsewhere on the board
/MCU/SPI_MISO: STM32F401RET6.22 (PA6); also elsewhere on the board
/MCU/SPI_MOSI: STM32F401RET6.23 (PA7); also elsewhere on the board
/MCU/SPI_SCK: STM32F401RET6.21 (PA5); also elsewhere on the board
/MCU/SWCLK: STM32F401RET6.49 (PA14); also elsewhere on the board
/MCU/SWDIO: STM32F401RET6.46 (PA13); also elsewhere on the board
/MCU/Tx: STM32F401RET6.42 (PA9); also elsewhere on the board
/MCU/USB_D+: STM32F401RET6.45 (PA12); also elsewhere on the board
/MCU/USB_D-: STM32F401RET6.44 (PA11); also elsewhere on the board
GND: STM32F401RET6.12 (VSSA/VREF-), STM32F401RET6.18 (VSS), STM32F401RET6.31 (VSS), STM32F401RET6.47 (VSS), STM32F401RET6.63 (VSS); also elsewhere on the board
NRST1: STM32F401RET6.7 (NRST); also elsewhere on the board
unnamed 34: STM32F401RET6.60 (BOOT0); also elsewhere on the board
unnamed 35: STM32F401RET6.26 (PB0); also elsewhere on the board
unnamed 36: STM32F401RET6.30 (VCAP1); also elsewhere on the board
U_BTN1: STM32F401RET6.14 (PA0); also elsewhere on the board

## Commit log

2026-09-05 Add schematic progress images and components table
2026-09-05 Add schematic progress images to README
2026-09-05 Add link to schematic and PCB PDF
    Added a link to the schematic and PCB PDF in the README.
